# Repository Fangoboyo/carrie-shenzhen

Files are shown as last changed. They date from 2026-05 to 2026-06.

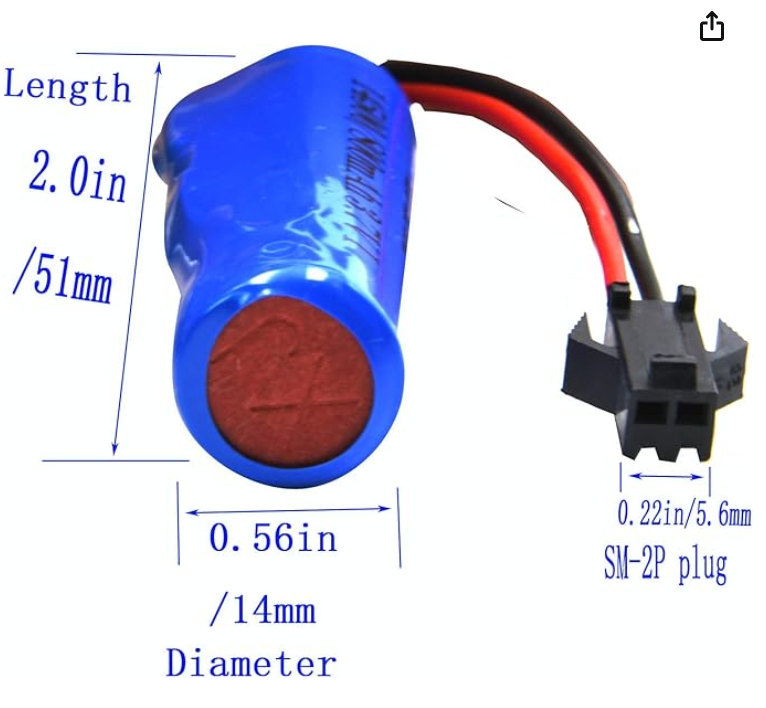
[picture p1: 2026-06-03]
materials/images/Pasted image 20260603162429.png

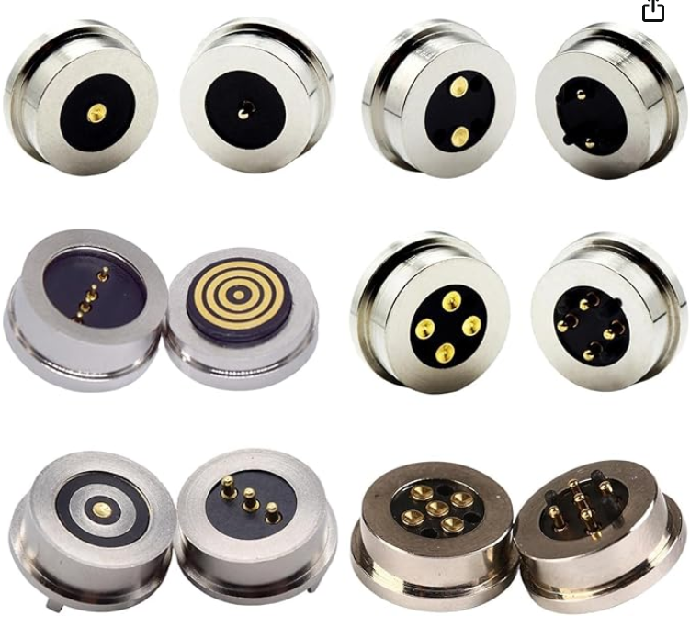
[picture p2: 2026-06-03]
materials/images/Pasted image 20260603162734.png

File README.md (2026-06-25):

# Carrie 🥕 — Embedded Audio/Video Recording Smart Pen

An embedded audio-recording smart pen shaped like a carrot, featuring a custom pot docking station for charging and data transfer. Powered by the Luckfox Pico Mini B (RV1103).

BILL OF MATERIALS IS IN [docs](/docs)



---

## Project Overview

A personal carry device in the shape of a carrot, Carrie is an interpretation of the carrot pen used by Judy Hopps in Zootopia. It's built with a microphone and a camera, integrated into the tiny form factor of a pen, and powered by an embedded Linux microcontroller (Luckfox Pico Mini B) on a custom PCB. With the click of a button, Carrie records 1080p footage at 30 FPS with audio, making sure you never forget to record those memorable moments. Then, simply take off the cap and plug the pen into the pot docking station to transfer your video files to a host computer and charge Carrie's battery.

---

## Why?

All 4 of the team members of this project are High School seniors. At the end of the year, many of the people who we have spent a majority of our lives with will be leaving to colleges across the world. It's easy to say that you'll keep in touch and commit to sending pictures and videos often of what you do everyday, but it's often a promise that is neglected not from a lack of care, but from the nature of experiencing an event; your first thought isn't always to start recording. With a personal carry device in such a form factor, Carrie serves as an always present, physical reminder of that promise. In this way, it helps old friends reconnect and stay connected.

---

## Directory Structure

```
├── docs/                           # Project documentation, Zines, and planning
│   ├── planning/                   # Vault planning notes and Technical Canvas
│   │   ├── notes/                  # Detailed engineering notes (display, GPIO, recording, etc.)
│   │   └── technical_overview.canvas # Visual concept overview
│   ├── bill_of_materials.csv       # Master Bill of Materials (BOM) with links & costs
│   └── zine.pdf                    # Creative project documentation
├── hardware/                       # Mechanical and Electrical designs
│   ├── cad/                        # Fusion 360 & STEP models
│   │   ├── individual_parts/       # Separate CAD files for components
│   │   └── README.md               # CAD specific notes & instructions
│   └── pcb/                        # KiCad PCB designs
│       ├── battery_charger/        # Carrot power regulation and battery charger PCB
│       ├── carry/                  # Main controller and breakout board PCB
│       ├── dirt/                   # Pot wiring junction PCB (V1)
│       └── dirt2/                  # Pot wiring junction PCB (V2)
├── firmware/                       # Source code for microcontrollers
│   ├── carrot/                     # RV1103 C code (Camera, Audio, and GPIO controls)
│   └── pot/                        # ESP8266 display driver code (.ino)
├── materials/                      # Detailed component datasheet notes & summaries
│   ├── bms/                        # Battery Management System notes (MCP73831, DW01A, etc.)
│   ├── images/                     # Component reference photos
│   └── *.md                        # Individual parts summaries (LCD, Microphone, Pogo, etc.)
└── platform/                       # React frontend & PocketBase/Bun backend dashboard
```

---

## Step-by-Step Build & Replication Guide

Follow this guide to replicate both the carrot pen (Carrie) and the docking station (Pot).

---

### 1. Bill of Materials (BOM)
Refer to the detailed master [Bill of Materials](docs/bill_of_materials.csv) for pricing, sourcing links, and specifications.

*   **Compute (Pen):** [Luckfox Pico Mini B (RV1103)](materials/esp32.md) - Linux SBC
*   **Sensor (Pen):** [SC3336 3MP Camera Module](materials/lcd_display.md) (CSI interface)
*   **Audio (Pen):** [SPH0655 Digital MEMS Microphone](materials/microphone.md)
*   **Battery (Pen):** 3.7V 800mAh Li-ion battery (size 14500 cell)
*   **Power (Pen):** Custom charger PCB with [MCP73831T-2A Charger IC](materials/bms/mcp73831.md)
*   **Indicator (Pen):** SunLED XZVGMDK53W-9 (bi-color Red/Green SMD LED)
*   **Compute (Pot):** [ESP8266 Dev Board](materials/esp32.md) (Wemos D1 Mini or similar)
*   **Display (Pot):** [ILI9341 320x240 SPI Touchscreen Display](materials/lcd_display.md)
*   **Docking Junction:** 4-pin Magnetic Contact POGO pins (5V, GND, D+, D-)
*   **Enclosure:** Orange/Green PLA filament, PLA glue.

---

### 2. Schematics & Electrical Design
The electrical system is divided between the Pen and the Pot. Schematics can be reviewed inside the [KiCad PCB Projects](hardware/pcb/).

#### A. The Pen (Carrie)
The pen uses two PCBs:
1.  **Main Board (`hardware/pcb/carry/`):** Hosts the Luckfox Pico Mini B. Routes the camera CSI ribbon, digital MEMS microphone (SPH0655), recording button, and status indicator LEDs.
2.  **Battery Charger Board (`hardware/pcb/battery_charger/`):** Features the [MCP73831T](materials/bms/mcp73831.md) charge controller, protection circuit (DW01A + FS8205A), and matches the bottom shape of the pen where the 4 magnetic contact pads reside.

##### Main Compute Module: Embedded Luckfox Pico Mini B

| Luckfox Pico Mini B (2D Layout) | Luckfox Pico Mini B (3D Render) |
| :---: | :---: |
| luckfox_2d | luckfox_3d |

*Figure 2: The RV1103-based Luckfox Pico Mini B development board used as the central Linux-based camera controller.*

##### Input: Audio & Video

| Microphone Breakout | CSI Camera Module |
| :---: | :---: |
| Microphone Pinout | SC3336 CSI Camera |

*Figure 3: Layouts for the digital SPH0655 MEMS Microphone and the SC3336 3MP CSI camera module.*

##### Power Management: MCP73831T-2A

| Charge Controller Chip | 2D Layout Routing | 3D Board Design |
| :---: | :---: | :---: |
| MCP73831 Chip | PCB 2D Layout | PCB 3D Design |

*Figure 4: The custom power board containing the MCP73831 charge management IC and protection circuits to safely regulate the 14500 Li-ion battery.*

##### Status Indicator: SunLED XZVGMDK53W-9
XZVGMDK53W-9 SMD LED

*Figure 5: Bi-color (Red/Green) SMD status indicator LED for tracking recording states.*

---

#### B. The Pot (Docking Station)
The pot PCB (`hardware/pcb/dirt2/`) aggregates connections for the ESP8266 Dev Board, ILI9341 SPI Display, and a Y-Junction cable to split power and USB data signals.

##### Embedded ESP8266 Board

| 3D Model | 2D Design |
| :---: | :---: |
| ESP8266 3D Model | ESP8266 2D Design |

*Figure 6: Custom PCB interface housing the ESP8266, routing signals to the LCD and decoupling incoming USB lines.*

##### Display: ILI9341
ILI9341 SPI TFT Module

*Figure 7: SPI Serial TFT display used to display system telemetry and connection feedback.*

---

### 3. CAD & Mechanical Assembly
All model assets are stored in [hardware/cad/](hardware/cad/).

#### The Shell

| Camera Side Cutout | Button Side Cutout |
| :---: | :---: |
| Camera Front Face | Button Rear Face |

*Figure 8: Outer mechanical CAD model of the carrot-shaped casing showing camera aperture and button positioning.*

#### Internals

Internal Placement Top

Internal Placement Isometric

*Figure 9: Exploded and internal CAD views highlighting the structural ribs, battery clip, and PCB slots inside the carrot pen.*

#### Flowerpot Dock

| Isometric View | Front Cutaway | Back Enclosure |
| :---: | :---: | :---: |
| Pot Iso | Pot Cutaway | Pot Back |

| Display Bezel Fitting | Base Enclosure Layout | Underneath Routing |
| :---: | :---: | :---: |
| Pot Display Bezel | Pot Inner Board | Pot Routing |

| Receptacle Neck Alignment | | |
| :---: | :---: | :---: |
| Pot Interface | | |

*Figure 10: Assembly CAD breakdowns of the flowerpot dock housing the display, wiring channels, and internal board mounts.*

#### POGO Pins for Data Transfer
We use a magnetic, spring-loaded POGO pin port at the bottom interface of the carrot and inside the pot neck to route data and charge signals.

POGO Pin Configuration

*Figure 11: The 4-pin magnetic layout routing 5V, GND, D+, and D- for toolless charging and storage connection.*

---

### 4. Firmware Build & Flashing Guide

#### A. Pen Firmware (RV1103)
The pen runs Buildroot Linux. Its C firmware is compiled inside a Docker Dev Container to manage target environment dependencies.

1.  **Launch Container:**
    Open the [firmware/carrot/](firmware/carrot/) directory in VS Code. It will prompt you to reopen in the dev container. Under the hood, this loads the `Dockerfile` from [firmware/carrot/.devcontainer/Dockerfile](firmware/carrot/.devcontainer/Dockerfile) which installs the cross-compiler toolchain `arm-rockchip830-linux-uclibcgnueabihf` and Rockchip Media Process Interface (RKMPI) headers.
2.  **Build Code:**
    Run the compile script:
    ```bash
    ./build.sh main
    ```
    This script cross-compiles:
    *   `main.c` (Core thread controller)
    *   `gpio/gpio.c` (Button interrupt and state control)
    *   `recorder/camera_recorder.c` (Uses RKMPI to fetch H.264 video streams from hardware framebuffers)
3.  **Deployment via ADB:**
    The script automatically runs `adb push` over the USB bridge to load the executable into the Luckfox:
    ```bash
    # Pushes binary and marks executable
    adb push main /root/
    adb shell "chmod +x /root/main"
    ```
    To test instantly, run:
    ```bash
    adb shell /root/main
    ```

#### B. Pot Display Firmware (ESP8266)
1.  Open the [firmware/pot/](firmware/pot/) folder in Arduino IDE.
2.  Install the **TFT_eSPI** library through the Library Manager.
3.  Copy/configure the correct pin assignments (CS, DC, RST, LED) in the `User_Setup.h` file located inside the `TFT_eSPI` library folder directory to match the ESP8266 pinout.
4.  Build and upload [displaydriver.ino](firmware/pot/displaydriver.ino) to your ESP8266 over serial USB.

---

### 5. Testing & Verification

1.  **Hardware Self-Test:** Connect the carrot pen to your PC. A solid green light indicates full charge; red/orange indicates active charging.
2.  **GPIO Check:** Run the compiled binary [gpio_input](firmware/carrot/gpio/gpio_input.c) to verify button state changes:
    ```bash
    ./build.sh gpio
    ```
3.  **Video Stream Test:** Run the `recorder` profile to verify image sensor capture and H.264 stream writing:
    ```bash
    ./build.sh recorder
    # Run on board: adb shell /root/camera_recorder_demo
    ```
4.  **Full Loop Recording:** Tap the physical button on the carrot casing. The indicator LED flashes to signal recording. Push the button again to stop.
5.  **Docking & Transfer:** Dock the pen in the Pot. The LCD screen should light up, showing connection telemetry. The PC will recognize a USB mass storage device or an ADB network interface. 
6.  **Web Dashboard Sync:** Start the React platform. Use the dashboard to fetch files from the docked pen and stream them directly onto Google Drive.
### Web Platform Dashboard
Okay I'm going to cut the formal documentation-speech for this part because im genuinely so proud of this website, it lets you plug your pot directly into your computer, and the browser is able to take the datastream from the USB and directly upload it to youtube for infinite free storage. All of the components are super animated like the books float and flip on their own, they rotate, they blur, all done with just tailwind. It genuinely took such a long time but adds an incredibly integrated aspect of the project that just brings everything together.

Web Platform Dashboard Mockup

*Figure 1: React-based web dashboard displaying scrapbook video feeds synced from the carrot pen.*

For more details on the design, code operations, and custom hardware modules, see the docs folder, where obsidian canvases draw out everything overviewing the project.

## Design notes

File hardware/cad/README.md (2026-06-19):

\#CAD README

\##General Notes

The entire CAD can be found in the FINAL files.

The models are split into parts, and are meant to be printed the way they are separated (one side of carrot, other half, one half of pot, other half, and individual parts that are inserted).

Pictures of complete models and renders of the carrot and the pot can be found in the main README file.

Individual parts are found in the Individual Parts Folder. 

Some individual parts don't contain their own file, and are in other files (such as some of the mounting/holding mechanisms, which exist in the carrot file).

There are some parts that are just created within the FINAL file, and do not exist in any other file.

\##Part Mounting/Connecting Parts

During testing, we found that due to the size of our project and the size of the printer nozzle, all of the joints that we created were extremely weak. This made us resort to testing just using the friction between the parts, which while working, are not reliable.

To fortify this approach, when we build our project, we will utilize 3D modeling glue (PLA glue), to directly create a connection in addition to cylindrical connectors. 

\##Parts

Some of the parts in the build are not apart of what is 3D printed. In the Carrot, you will see 3 rectangular boxes, with the middle one with some stuff sticking out. Those 3 are just placeholders for where our RV1103 Pico Mini Linux SBC, Carry PCB, and Battery Regulator will be. 

The battery will be placed in the battery holder, and will be stopped on the top by the part on the other side of the carrot, so there is no vertical movement.

The camera is held at the top of the carrot (toward the leaf), with cylinders that fit inside it's mounting holes, and is slotted in there.

The PCB and microcontroller for the Pot will be slotted at the bottom of the Pot.

The PCB and microcontroller for both the Pot and the Carrot will be connected to each other via pin headers. These pin headers will be cut to be shorter than standard size, in order to fit inside compartments. 

Components will be connected to each other via wiring and soldering. 

The Cap and the Leaf are attached using a the coil method (like a bottle cap).

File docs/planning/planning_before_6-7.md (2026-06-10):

Albert - solidify component list
what components would we use
why use this one
why others wont work

Youcheng
ORDER PCB

Q1: How can we rework the MCP pin to be off of the PCB in order to make a seperate breakout board regulator

![[Pasted image 20260605001627.png]]

Q2: explain what the STAT pin does IN DETAIL PLEASE (voltage? current direction?) why are specific resistance values picked. Schematic should be corrected. Details of each part of the PCB needs to be documented. (maybe push some documentation onto the obsidian project??)

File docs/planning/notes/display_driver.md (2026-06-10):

```c++
#include <SPI.h>
#include <TFT_eSPI.h>

// Invoke the library. It automatically pulls the pins from User_Setup.h
TFT_eSPI tft = TFT_eSPI(); 

void setup() {
  Serial.begin(115200);

  // 1. Initialize the hardware SPI bus and the display
  tft.init();

  // 2. Set screen rotation 
  // 0 = Portrait, 1 = Landscape, 2 = Portrait Inverted, 3 = Landscape Inverted
  tft.setRotation(1);

  // 3. Clear the screen to a solid color
  tft.fillScreen(TFT_BLACK);

  // --- DRAWING THE INTERFACE ---

  // Draw a top status bar
  tft.fillRect(0, 0, 320, 30, TFT_BLUE); 

  // Setup text formatting
  tft.setTextColor(TFT_WHITE, TFT_BLUE); // Foreground, Background (prevents text overlapping mess)
  tft.setTextSize(2); // Multiplier of the base font size
  
  // Print text to the status bar
  tft.setCursor(10, 8);
  tft.println("SYSTEM ONLINE");

  // Placeholder
  tft.setTextColor(TFT_GREEN, TFT_BLACK);
  tft.setTextSize(3);
  tft.setCursor(10, 60);
  tft.println("Temp: 42 C");
}

void loop() {
}
```

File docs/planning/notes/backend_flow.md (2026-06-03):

# System Architecture

## Backend Flow

The backend is built with Bun's native HTTP server (`Bun.serve`) and a local `bun:sqlite` database. It handles Google OAuth, session management, and piping uploads directly to the Google Drive API.

```mermaid
sequenceDiagram
    participant Client
    participant Server as Bun Server
    participant DB as SQLite DB
    participant GoogleAuth as Google OAuth
    participant GoogleDrive as Google Drive API

    %% Authentication Flow
    rect rgb(240, 248, 255)
        Note over Client, GoogleAuth: 1. Authentication & Session
        Client->>Server: GET /auth/google
        Server-->>Client: 302 Redirect to Google Auth URL
        Client->>GoogleAuth: User logs in & grants consent
        GoogleAuth-->>Server: GET /auth/callback?code=xyz
        Server->>GoogleAuth: Exchange code for Tokens
        GoogleAuth-->>Server: Access & Refresh Tokens
        Server->>DB: Upsert User & Generate API Key
        Server-->>Client: Set Session Cookie & Redirect to /
    end

    %% Feed Retrieval Flow
    rect rgb(255, 250, 240)
        Note over Client, DB: 2. Initial Data Load
        Client->>Server: GET /api/me (with Cookie)
        Server->>DB: Lookup user by Cookie ID
        DB-->>Server: User Data & API Key
        Server-->>Client: JSON { user }
        
        Client->>Server: GET /api/videos
        Server->>DB: SELECT * FROM videos JOIN users
        DB-->>Server: Feed Data
        Server-->>Client: JSON [ videos ]
    end

    %% Upload Flow
    rect rgb(240, 255, 240)
        Note over Client, GoogleDrive: 3. Video Upload
        Client->>Server: POST /api/upload (File + Bearer API_KEY)
        Server->>DB: Verify API_KEY
        DB-->>Server: Valid User Tokens
        Server->>GoogleDrive: Pipe File Stream (create)
        GoogleDrive-->>Server: Return Google Drive File ID
        Server->>DB: INSERT INTO videos (file_id, user_id)
        Server-->>Client: 200 OK (Upload Successful)
    end
```

[[Frontend Flow]]

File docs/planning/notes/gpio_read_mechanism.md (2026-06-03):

Before reading from a pin, a GPIO pin needs to be exported:
```C
int gpio_export(int gpio)
{
    char dir[80];
    snprintf(dir, sizeof(dir), GPIO_ROOT "/gpio%d", gpio);
    if (access(dir, F_OK) == 0) return 0;   /* already exported */

    char buf[16];
    snprintf(buf, sizeof(buf), "%d", gpio);
    if (sysfs_write(GPIO_ROOT "/export", buf) < 0) {
        fprintf(stderr, "  [!] Export failed — is gpio%d valid on this kernel?\n", gpio);
        return -1;
    }
    return 0;
}
```

 ` snprintf` writes data into char array `buf`. This is necessary because the way you read GPIO pins in a Linux based development board is through accessing the GPIO file.

After the pin is exported, it is read through:
```C
int gpio_read(int gpio)
{
    char path[80];
    snprintf(path, sizeof(path), GPIO_ROOT "/gpio%d/value", gpio);
    FILE *f = fopen(path, "r");
    if (!f) { perror("  [!] read value"); return -1; }
    
    int v = -1;
    fscanf(f, "%d", &v);
    fclose(f);
    return v;
}
```

taking the output of `/gpio%d/value` as a file and returning it as a value

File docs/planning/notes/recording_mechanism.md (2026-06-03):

#### Writer Thread
Each iteration of the recording loop dequeues one encoded stream packet from the Video Encoder (VENC) channel, writes it to disk, then releases the buffer back to the codec.  `RK_MPI_VENC_GetStream()` blocks up to `timeout_ms` milliseconds, so the thread is never busy-spinning.

```c
VENC_STREAM_S stream;
VENC_PACK_S   packs[8];
memset(&stream, 0, sizeof(stream));
memset(packs, 0, sizeof(packs));
stream.pstPack = packs;
```

After initializing the stream and pack with values 0, we get the next available frame:

```c
RK_S32 ret = RK_MPI_VENC_GetStream(g_cfg.venc_chn, &stream, timeout_ms);
```

`RK_MPI_VENC_GetStream` gets the next available frame from the `g_cfg.venc_chn` which is our main channel, into our `VENC_STREAM_S stream` with a timeout.

We then check if the frame was successfully retrieved:

```c
if (ret == RK_ERR_VENC_BUF_EMPTY) {
	/* No frame ready yet — loop and try again */
    continue;
}
if (ret != RK_SUCCESS) {
    LOG_ERR("RK_MPI_VENC_GetStream failed (0x%08x)", (unsigned)ret);
    break;
}
```

After the frame is output into our buffer, we can start "stitching" the packets together, by looping through the Network Abstraction Layer (NAL) units and:

```c
VENC_PACK_S *pack = &stream.pstPack[i]; // current packet in loop

void *data = RK_MPI_MB_Handle2VirAddr(pack->pMbBlk);
```

The Rockchip hardware encoder operates in physical memory. It drops the video data into a hardware memory block `pMbBlk`.

The C program runs in Linux "user space" and cannot directly touch physical hardware memory.

`RK_MPI_MB_Handle2VirAddr` acts as a translator. It takes the hardware's memory handle and gives back a standard C pointer (data - a "Virtual Address") that your CPU can safely read. Essentially, giving an API representation that lets you interact with the hardware memory across the linux abstraction layer.

Finally, we can validate the packet packet length is not empty through `pack->u32Len (Memory length) > 0` and `data (Memory address) != null`. If this is validated, we can then write into the `g_out_file` from address `data` for `pack->u32Len` length of data.

```c
if (pack->u32Len > 0 && data != NULL) { fwrite(data, 1, pack->u32Len, g_out_file); }
```

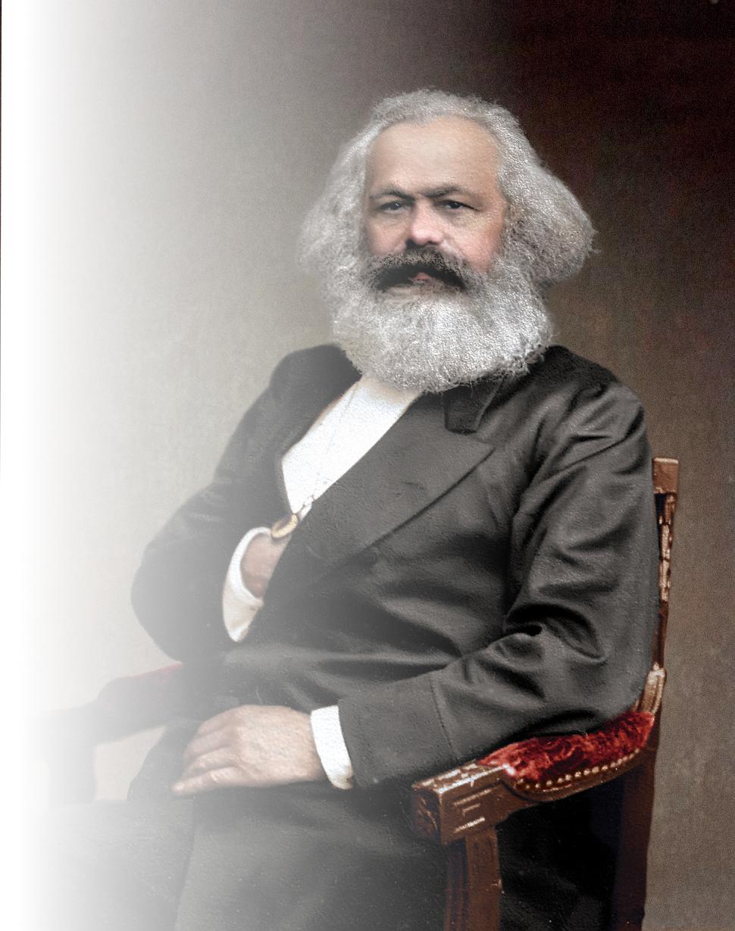
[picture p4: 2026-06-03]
platform/src/assets/marx.png

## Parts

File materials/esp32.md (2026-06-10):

[Amazon](https://www.amazon.com/dp/B081CSJV2V?ref_=ppx_hzsearch_conn_dt_b_fed_asin_title_2)

[[LCD Display (Touchscreen) - Arrived]] Takes:

| ESP Pin | Touchscreen |
| --- | --- |
| 3v3 | VCC |
| 3v3 | LED |
| GND | GND |

![[Pasted image 20260603140626.png]]

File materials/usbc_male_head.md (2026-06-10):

Stripped male head of a USBC cable, with the D+/- exposed

Plugs into the USBC female port on the development board
![[Pasted image 20260604230423.png]]

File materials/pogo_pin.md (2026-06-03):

[Amazon](https://www.amazon.com/Magnetic-Connector-Female-Socket-Charging/dp/B0DJ26RV19/ref=sr_1_6?sr=8-6&th=1)

| PIN | Usage |
| --- | --- |
| D+ | D+ on USBC Male -> POGO -> Dirt pile |
| D- | D- on USBC Male -> POGO -> Dirt pile |
| 5V VBUS | Dirt Pile -> POGO -> Battery Regulator |
| GND | Dirt Pile -> POGO -> Battery Regulator |
![[Pasted image 20260603162734.png]]

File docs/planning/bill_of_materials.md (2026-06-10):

[[LCD Display (Touchscreen) - Arrived]]
[[POGO Pin - Arrived]]
[[ESP32 - Arrived]]
[[Microphone - Arrived]]

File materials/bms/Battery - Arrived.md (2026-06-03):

[Amazon](https://www.amazon.com/Blomiky-Rechargeable-Battery-Charger-Amphibious/dp/B08Q45XQKW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)

![[Pasted image 20260603162429.png]]

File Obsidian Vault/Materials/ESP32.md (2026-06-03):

[Amazon](https://www.amazon.com/dp/B081CSJV2V?ref_=ppx_hzsearch_conn_dt_b_fed_asin_title_2)

[[LCD Display (Touchscreen)]] Takes:

| ESP Pin | Touchscreen |
| --- | --- |
| 3v3 | VCC |
| 3v3 | LED |
| GND | GND |

![[Pasted image 20260603140626.png]]

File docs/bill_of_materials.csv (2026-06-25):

Part Name | Unit Part Price ($) | Unit Part Count | Part Cost Total ($) | Description | Part Link | Total:
RV1103 Pico Mini Linux SBC | 15 | 1 | 15 | Linux-based microcontroller board used as the main processing unit for dealing with audo/video recording and handles data | https://www.amazon.com/dp/B0CSSZFRR3 | 98.65
SPH0655 Digital MEMS Microphone | 1.69 | 1 | 1.69 | High-sensitivity digital MEMS microphone used for capturing voice an audio | https://www.digikey.com/en/products/detail/syntiant/SPH0655LM4H-1-8/11506911
SC3336 3MP Camera Module | 12.89 | 1 | 12.89 | 3MP compact camera module for capturing images and video footage | https://osoyoo.store/products/osoyoo-basic-starter-kit-with-uno-board-for-arduino-electronic-projects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
MCP73831T-2ACI/OT | 0.76 | 1 | 0.76 | Charger IC Lithium Ion/Polymer SOT-23-5 | https://www.digikey.com/en/products/detail/microchip-technology/MCP73831T-2ACI-OT/964301
SunLED XZVGMDK53W-9 | 0.35 | 1 | 0.35 | Green, Red 570nm Green, 630nm Red LED Indication - Discrete 2.1V Green, 1.95V Red 0603 (1608 Metric) | https://www.digikey.com/en/products/detail/sunled/XZVGMDK53W-9/8259057
Touch Screen Shield Display Module 320x240 SPI Serial ILI9341 with Touch Pen | 14.99 | 1 | 14.99 | Resistance based touchscreen LCD | https://www.amazon.com/Hosyond-Display-320x240-Compatible-Development/dp/B09XHJ9KRX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
Button | 5 | 1 | 5 | Simple electrical button | https://www.amazon.com/DAOKI-100Pcs-6x6x5mm-Momentary-Tactile/dp/B07X8T9D2Q?s=industrial
Orange PLA filament | 14.99 | 1 | 14.99 | 3D Printing Filament | https://www.amazon.com/Miailuy-Filament-Tangle-Free-Clog-Free-Compatibility/dp/B0FN46ZXRB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
PLA Glue | 8 | 1 | 8 | 3D Printing glue for PLA (casing needs to be glued together due to size restrictions preventing screw usage | https://www.amazon.com/ALECPEA-Printer-Glue-Resin-Models/dp/B0G3WYT51V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
Blomiky 2 Pack 3.7V 800mAh Li-ion Rechargeable Battery | 9.99 | 1 | 9.99 | 3.7V 800 mAh battery to power the carrot's microcontroller | https://www.amazon.com/Blomiky-Rechargeable-Battery-Charger-Amphibious/dp/B08Q45XQKW
ESP8266 | 14.99 | 1 | 14.99 | Microcontroller on the pot/holster to drive the touchscreen display | https://www.amazon.com/Hosyond-Wireless-Development-Compatible-Micropython/dp/B09SPWYS4B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

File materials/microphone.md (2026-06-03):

[Amazon](https://www.amazon.com/Adafruit-I2S-MEMS-Microphone-Breakout/dp/B06XNL2GBW)

![[Pasted image 20260603163029.png]]

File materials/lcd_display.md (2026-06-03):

[Amazon](https://www.amazon.com/Hosyond-Display-320x240-Compatible-Development/dp/B09XHJ9KRX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)

![[Pasted image 20260603153835.png]]

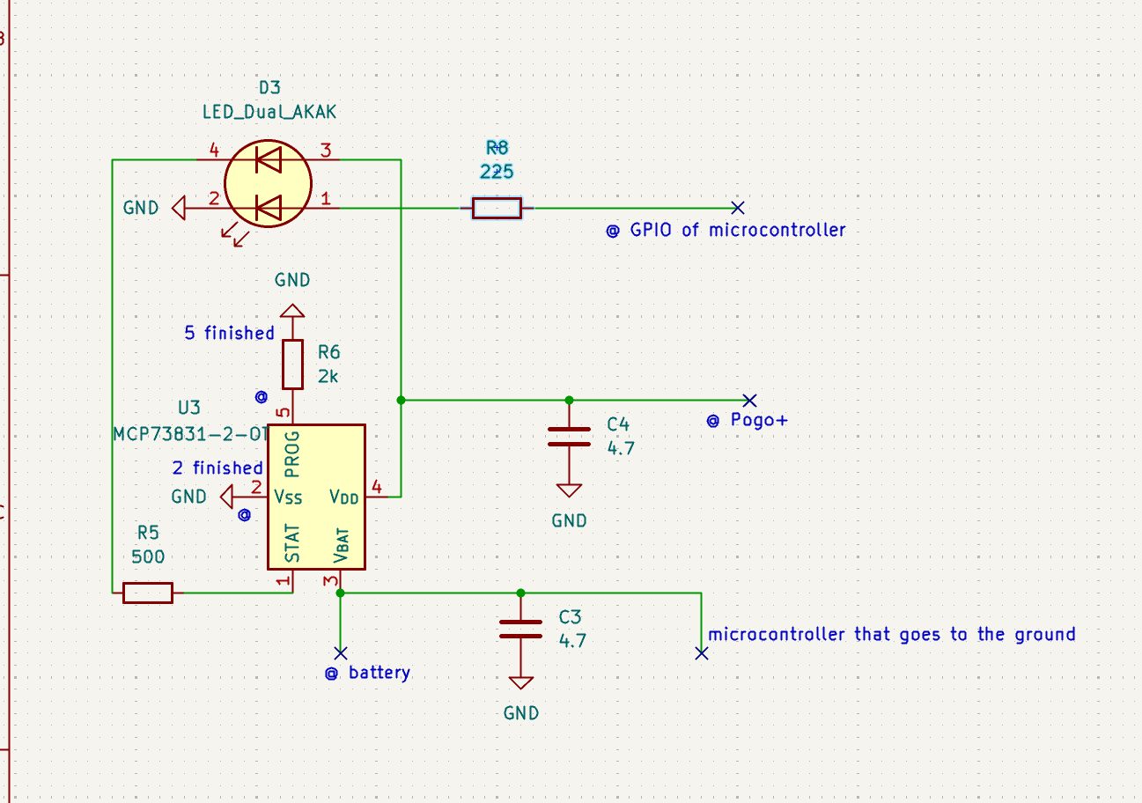
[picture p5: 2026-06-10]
materials/images/Pasted image 20260605001627.png

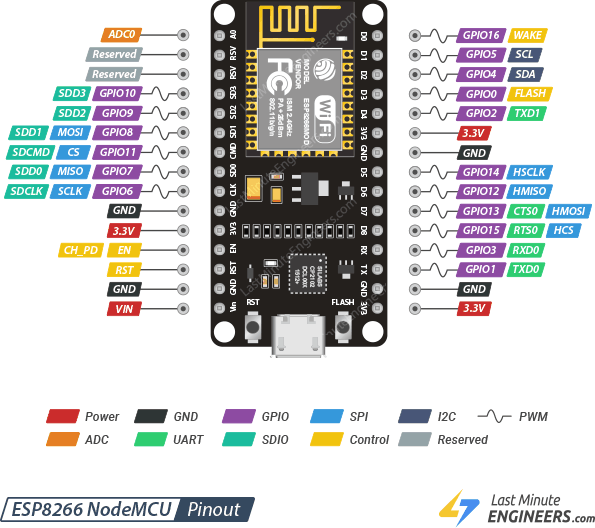
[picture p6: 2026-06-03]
materials/images/Pasted image 20260603140626.png

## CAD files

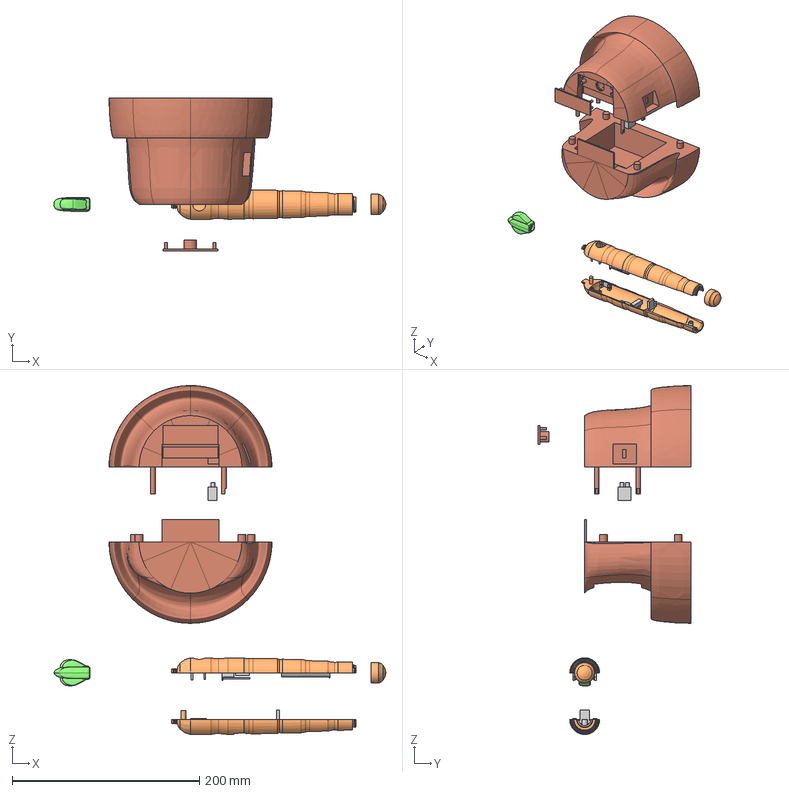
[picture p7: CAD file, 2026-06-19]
hardware/cad/FINAL.step
354.8 x 163.7 x 373.2 mm

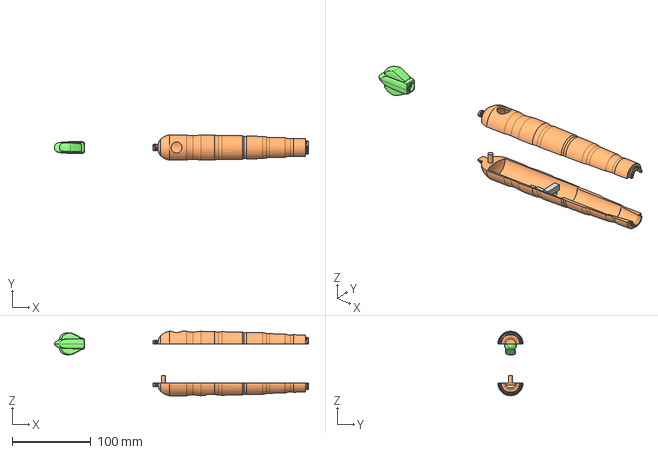
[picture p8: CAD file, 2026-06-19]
hardware/cad/individual_parts/Carrot.step
322.6 x 32.0 x 82.0 mm

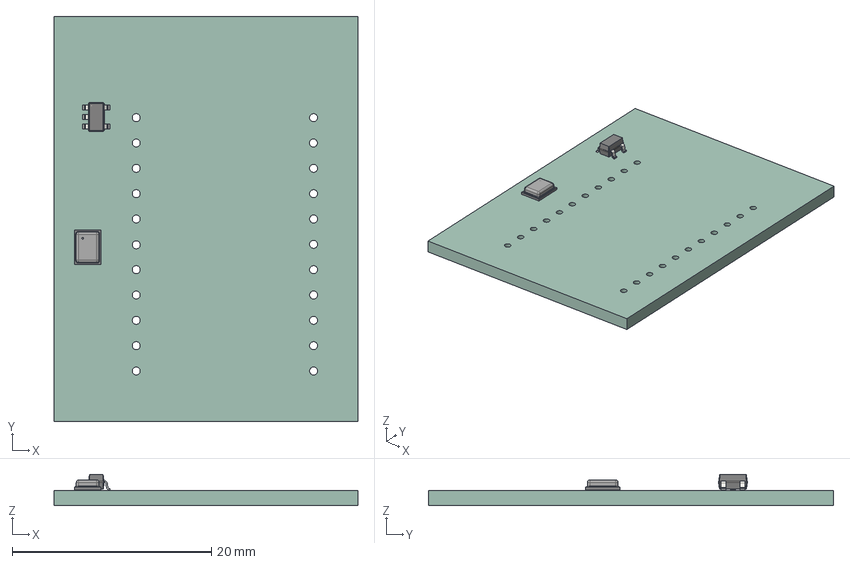
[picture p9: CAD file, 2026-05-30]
hardware/pcb/carry/.step
30.5 x 40.6 x 3.15 mm
SOT-23-5
Knowles_SPH0645LM4H-6_3.5x2.65mm
Carry_PCB

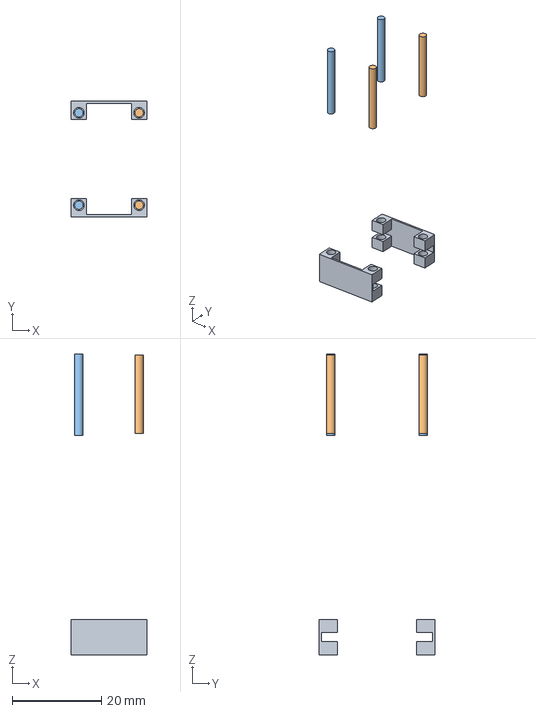
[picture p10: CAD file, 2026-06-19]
hardware/cad/individual_parts/Camera Support.step
17.0 x 26.0 x 67.5 mm

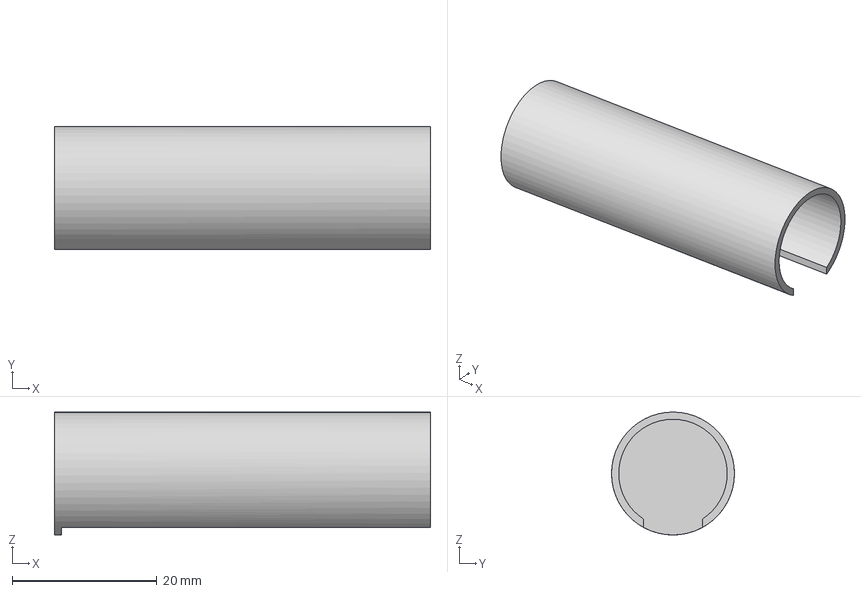
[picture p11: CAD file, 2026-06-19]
hardware/cad/individual_parts/Battery Holder.step
52.0 x 17.0 x 17.0 mm

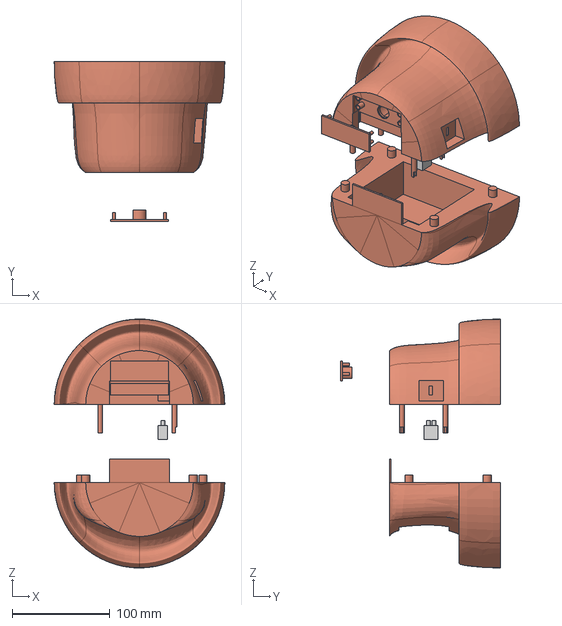
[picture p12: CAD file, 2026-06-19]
hardware/cad/individual_parts/Pot.step
174.3 x 163.7 x 254.3 mm

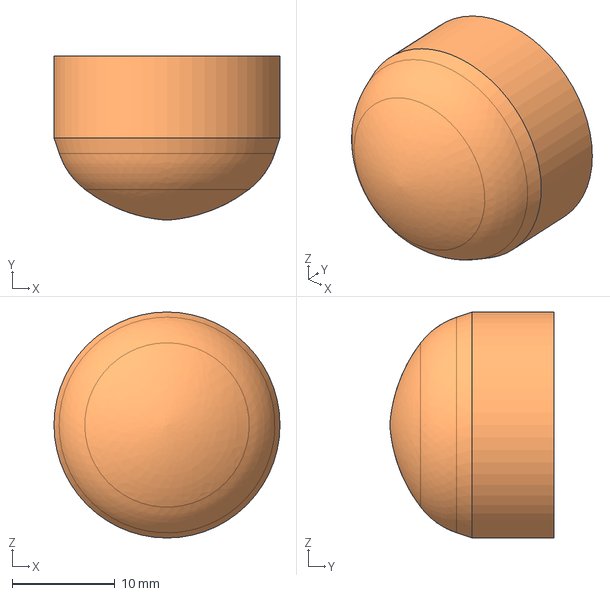
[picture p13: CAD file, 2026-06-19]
hardware/cad/individual_parts/Cap.step
22.0 x 16.0 x 22.0 mm

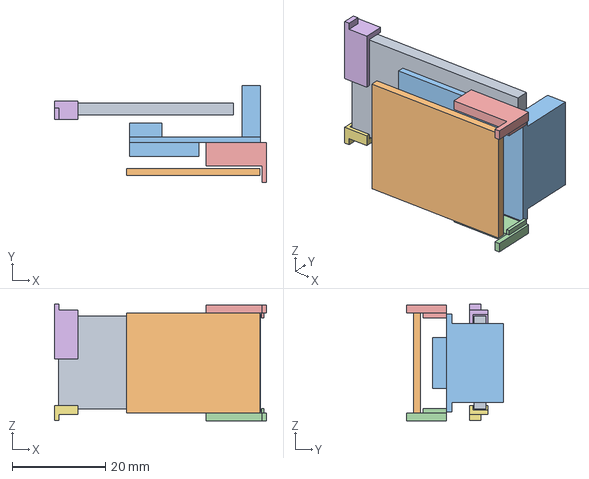
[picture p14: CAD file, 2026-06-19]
hardware/cad/individual_parts/PCB Slot.step
45.5 x 20.8 x 25.1 mm

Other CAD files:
hardware/cad/individual_parts/Battery Holder.f3d
hardware/cad/individual_parts/Camera Support.f3d
hardware/cad/individual_parts/Cap.f3d
hardware/cad/individual_parts/Carrot.f3d
hardware/cad/individual_parts/PCB Slot.f3d
hardware/cad/individual_parts/Pot.f3d

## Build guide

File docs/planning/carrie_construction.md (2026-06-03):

[[Technical overview.canvas]]

| Color | Significance |
| ----- | --- |
| Red | Power |
| Blue  | Data |
| Green | Display |

|     |
| --- |
|     |

[[Bill of Materials]]

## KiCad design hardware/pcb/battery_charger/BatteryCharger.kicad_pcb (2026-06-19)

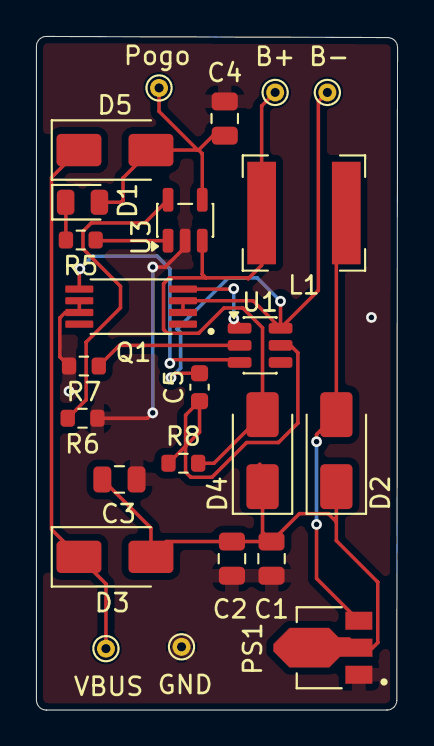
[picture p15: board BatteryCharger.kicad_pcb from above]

Board: 2 copper layers, 20.1 x 37.4 mm, 24 parts (0 on the bottom side), 14 nets.

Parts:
B+: B+; TestPoint_THTPad_D1.0mm_Drill0.5mm
B-: B-; TestPoint_THTPad_D1.0mm_Drill0.5mm
C1, C2: 12; C_0805_2012Metric
C3, C4: 4.7; C_0805_2012Metric
C5: 0.1; C_0603_1608Metric
D1: LED; LED_0805_2012Metric
D2, D3, D4, D5: SS14; D_SMA
GND: B-; TestPoint_THTPad_D1.0mm_Drill0.5mm
L1: 22; L_Bourns-SRN6028
PS1: ME2108A33P
Pogo: Pogo+; TestPoint_THTPad_D1.0mm_Drill0.5mm
Q1: FS8205A
R5: 470; R_0603_1608Metric
R6: 2k; R_0603_1608Metric
R7: 1k; R_0603_1608Metric
R8: 100; R_0603_1608Metric
U1: DW01A; SOT-23-6
U3: MCP73831; SOT-23-5
VBUS: Output 5V; TestPoint_THTPad_D1.0mm_Drill0.5mm

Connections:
GND: C1.2, C2.2, C3.2, C4.2, GND.1 (1_1), PS1.1 (VSS), Q1.6, Q1.7, R6.1, R7.2, U3.2 (V_{SS})
unnamed: C4.1, D1.2 (A), D5.2 (A), Pogo.1 (1_1), U3.4 (V_{DD})
unnamed: D1.1 (K), R5.2
unnamed: D2.2 (A), L1.2, PS1.3 (LX)
unnamed: C1.1, C2.1, C3.1, D2.1 (K), D3.2 (A), D4.1 (K), PS1.2 (VOUT)
unnamed: D3.1 (K), D5.1 (K), VBUS.1 (1_1)
unnamed: B+.1 (1_1), D4.2 (A), L1.1, R8.1, U3.3 (V_{BAT})
unnamed: R7.1, U1.2 (CS)
unnamed: B-.1 (1_1), C5.2, Q1.2, Q1.3, U1.6 (GND)
unnamed: Q1.5, U1.3 (OC)
unnamed: Q1.4, U1.1 (OD)
unnamed: C5.1, R8.2, U1.5 (VCC)
unnamed: R6.2, U3.5 (PROG)
unnamed: R5.1, U3.1 (STAT)

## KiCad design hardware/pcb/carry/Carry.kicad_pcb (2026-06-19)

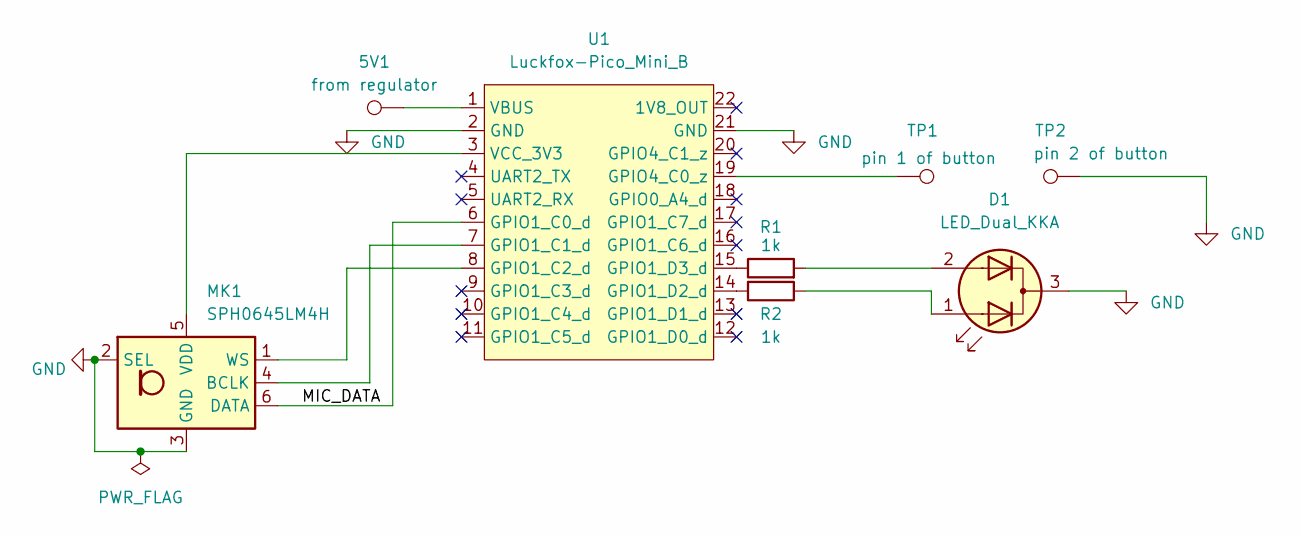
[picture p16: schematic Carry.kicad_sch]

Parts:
5V1: from regulator; TestPoint_THTPad_D1.0mm_Drill0.5mm
D1: LED_Dual_KKA; LED-L1T2_LUMILEDS
MK1: SPH0645LM4H; Knowles_SPH0645LM4H-6_3.5x2.65mm
R1, R2: 1k
TP1: pin 1 of button; TestPoint_THTPad_D1.0mm_Drill0.5mm
TP2: pin 2 of button; TestPoint_THTPad_D1.0mm_Drill0.5mm
U1: Luckfox-Pico_Mini_B; Luckfox_Pico_Mini_B

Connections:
/MIC_DATA: MK1.6 (DATA), U1.6 (GPIO1_C0_d)
GND: D1.3 (K), MK1.2 (SEL), MK1.3 (GND), TP2.1 (1_1), U1.2 (GND), U1.21 (GND)
unnamed: D1.1 (A1), R2.1
unnamed: D1.2 (A2), R1.2
unnamed: MK1.4 (BCLK), U1.7 (GPIO1_C1_d)
unnamed: MK1.5 (VDD), U1.3 (VCC_3V3)
unnamed: MK1.1 (WS), U1.8 (GPIO1_C2_d)
unnamed: R2.2, U1.14 (GPIO1_D2_d)
unnamed: R1.1, U1.15 (GPIO1_D3_d)
unnamed: TP1.1 (1_1), U1.19 (GPIO4_C0_z)
unnamed: 5V1.1 (1_1), U1.1 (VBUS)

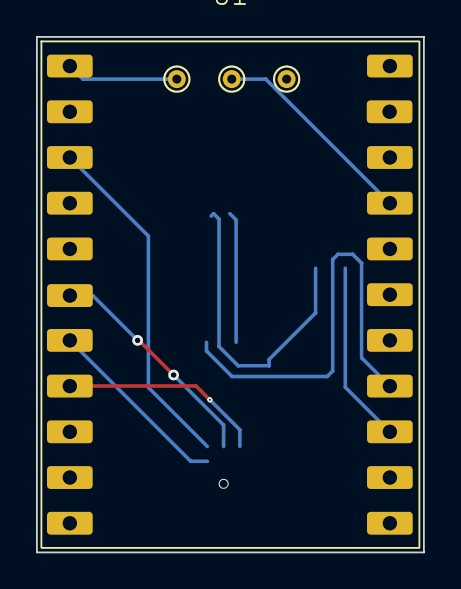
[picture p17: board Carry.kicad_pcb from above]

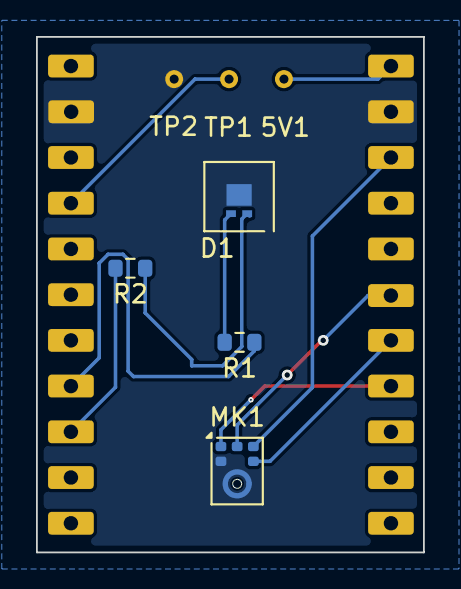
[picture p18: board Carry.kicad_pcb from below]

Board: 2 copper layers, 21.5 x 28.6 mm, 8 parts (4 on the bottom side), 11 nets.

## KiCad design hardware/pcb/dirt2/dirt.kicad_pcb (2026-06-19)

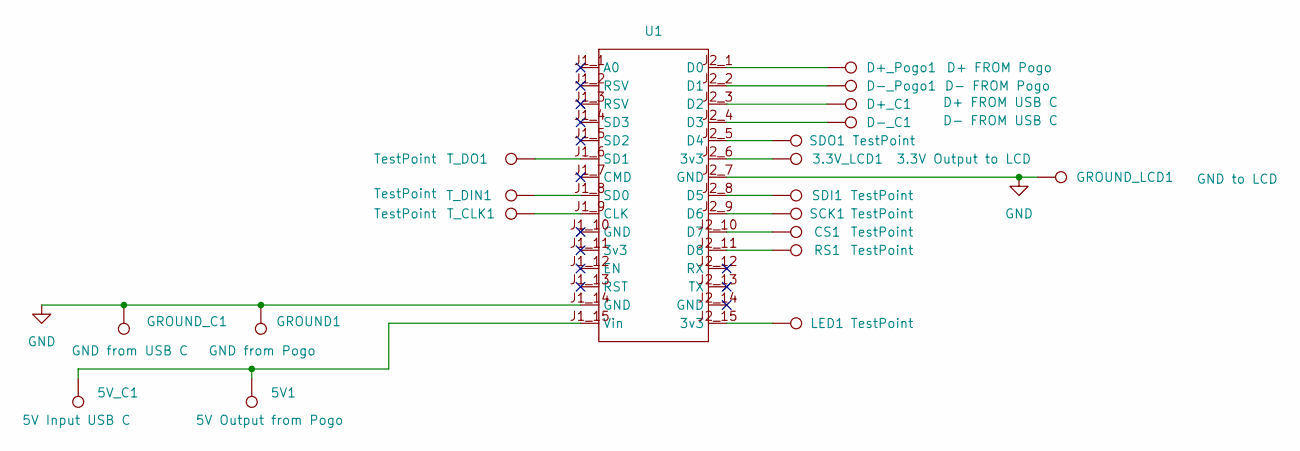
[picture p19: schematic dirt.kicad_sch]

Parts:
3.3V_LCD1: 3.3V Output to LCD; TestPoint_THTPad_D1.0mm_Drill0.5mm
5V1: 5V Output from Pogo; TestPoint_THTPad_D1.0mm_Drill0.5mm
5V_C1: 5V Input USB C; TestPoint_THTPad_D1.0mm_Drill0.5mm
CS1: TestPoint; TestPoint_THTPad_D1.0mm_Drill0.5mm
D+_C1: D+ FROM USB C; TestPoint_THTPad_D1.0mm_Drill0.5mm
D+_Pogo1: D+ FROM Pogo; TestPoint_THTPad_D1.0mm_Drill0.5mm
D-_C1: D- FROM USB C; TestPoint_THTPad_D1.0mm_Drill0.5mm
D-_Pogo1: D- FROM Pogo; TestPoint_THTPad_D1.0mm_Drill0.5mm
GROUND1: GND from Pogo; TestPoint_THTPad_D1.0mm_Drill0.5mm
GROUND_C1: GND from USB C; TestPoint_THTPad_D1.0mm_Drill0.5mm
GROUND_LCD1: GND to LCD; TestPoint_THTPad_D1.0mm_Drill0.5mm
LED1: TestPoint
RS1: TestPoint; TestPoint_THTPad_D1.0mm_Drill0.5mm
SCK1: TestPoint; TestPoint_THTPad_D1.0mm_Drill0.5mm
SDI1: TestPoint; TestPoint_THTPad_D1.0mm_Drill0.5mm
SDO1: TestPoint; TestPoint_THTPad_D1.0mm_Drill0.5mm
T_CLK1: TestPoint; TestPoint_THTPad_D1.0mm_Drill0.5mm
T_DIN1: TestPoint; TestPoint_THTPad_D1.0mm_Drill0.5mm
T_DO1: TestPoint; TestPoint_THTPad_D1.0mm_Drill0.5mm
U1: (no value)

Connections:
GND: GROUND1.1 (1_1), GROUND_C1.1 (1_1), GROUND_LCD1.1 (1_1), U1.J1_14 (GND), U1.J2_7 (GND)
unnamed: 3.3V_LCD1.1 (1_1), U1.J2_6 (3v3)
unnamed: LED1.1, U1.J2_15 (3v3)
unnamed: T_CLK1.1 (1_1), U1.J1_9 (CLK)
unnamed: D+_Pogo1.1 (1_1), U1.J2_1 (D0)
unnamed: D-_Pogo1.1 (1_1), U1.J2_2 (D1)
unnamed: D+_C1.1 (1_1), U1.J2_3 (D2)
unnamed: D-_C1.1 (1_1), U1.J2_4 (D3)
unnamed: SDO1.1 (1_1), U1.J2_5 (D4)
unnamed: SDI1.1 (1_1), U1.J2_8 (D5)
unnamed: SCK1.1 (1_1), U1.J2_9 (D6)
unnamed: CS1.1 (1_1), U1.J2_10 (D7)
unnamed: RS1.1 (1_1), U1.J2_11 (D8)
unnamed: T_DIN1.1 (1_1), U1.J1_8 (SD0)
unnamed: T_DO1.1 (1_1), U1.J1_6 (SD1)
unnamed: 5V1.1 (1_1), 5V_C1.1 (1_1), U1.J1_15 (Vin)

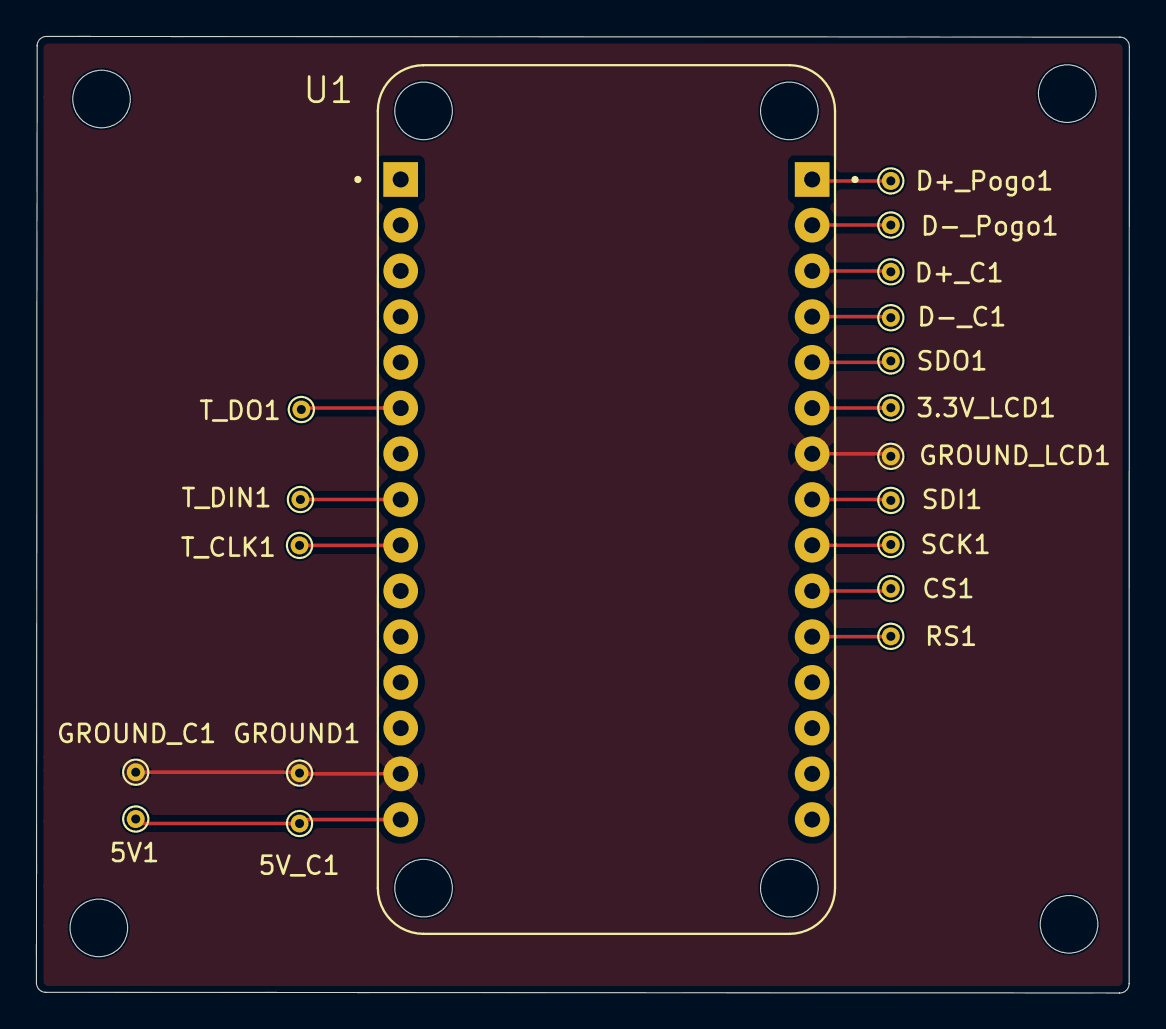
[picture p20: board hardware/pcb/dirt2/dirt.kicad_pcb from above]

Board: 2 copper layers, 60.7 x 53.1 mm, 19 parts (0 on the bottom side), 15 nets.

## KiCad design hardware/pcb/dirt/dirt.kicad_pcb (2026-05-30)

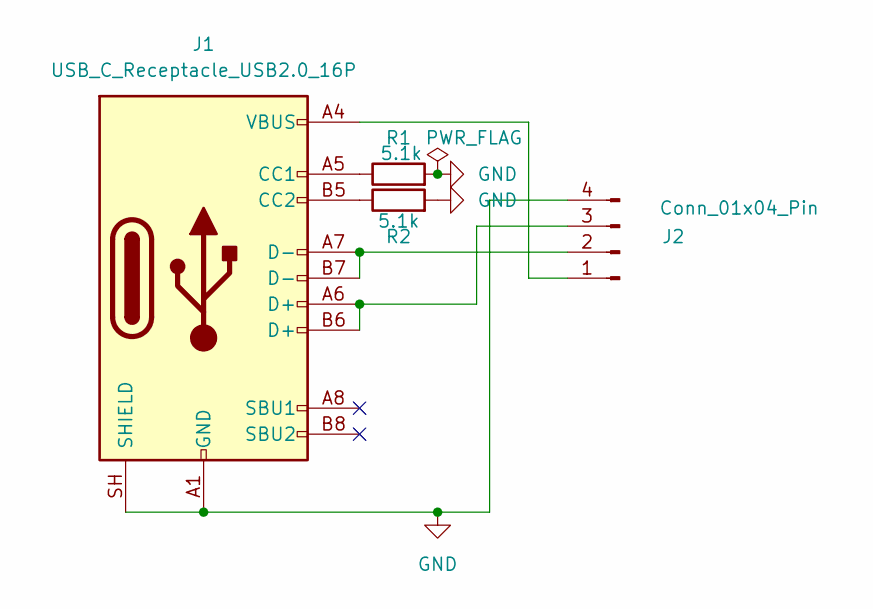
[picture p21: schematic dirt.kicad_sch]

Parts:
J1: USB_C_Receptacle_USB2.0_16P; USB_C_Receptacle_HRO_TYPE-C-31-M-12
J2: Conn_01x04_Pin; PinHeader_1x04_P2.54mm_Vertical_SMD_Pin1Left
R1, R2: 5.1k; R_0805_2012Metric

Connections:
GND: J1.A1 (GND), J1.A12 (GND), J1.B1 (GND), J1.B12 (GND), J1.SH (SHIELD), J2.4, R1.2, R2.2
unnamed: J1.A5 (CC1), R1.1
unnamed: J1.B5 (CC2), R2.1
unnamed: J1.A4 (VBUS), J1.A9 (VBUS), J1.B4 (VBUS), J1.B9 (VBUS), J2.1
unnamed: J1.A7 (D-), J1.B7 (D-), J2.2
unnamed: J1.A6 (D+), J1.B6 (D+), J2.3

Board: 2 copper layers, 4 parts (0 on the bottom side), 6 nets, no tracks yet.

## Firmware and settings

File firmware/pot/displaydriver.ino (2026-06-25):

#include <SPI.h>
#include <TFT_eSPI.h>

TFT_eSPI tft = TFT_eSPI();

// UI State variables
enum SystemState {
  STATE_DISCONNECTED,
  STATE_CONNECTED,
  STATE_SYNCING,
  STATE_SYNC_COMPLETE,
  STATE_EJECTED
};

SystemState currentState = STATE_CONNECTED;
SystemState previousState = STATE_DISCONNECTED;

// Telemetry state
int batteryPercent = 78;
float batteryVoltage = 3.92;
int chargeCurrent = 420; // mA
int syncProgress = 0;
String currentSyncFile = "video_03.h264";

// Interactive Backlight dummy state
bool backlightOn = true;

// Timing variables for simulation
unsigned long lastUpdate = 0;
unsigned long lastTouchDebounce = 0;

void setup() {
  Serial.begin(115200);
  tft.init();
  tft.setRotation(1); // Landscape (320x240)
  tft.fillScreen(TFT_BLACK);
  
  // Calibrate touch sensor (default coordinates mapping)
  uint16_t calData[5] = { 275, 3620, 264, 3532, 1 };
  tft.setTouch(calData);

  drawBaseLayout();
}

void drawBaseLayout() {
  tft.fillScreen(TFT_BLACK);
  
  // Header Status Bar
  tft.fillRect(0, 0, 320, 30, TFT_NAVY);
  tft.setTextColor(TFT_WHITE, TFT_NAVY);
  tft.setTextSize(2);
  tft.setCursor(10, 8);
  tft.print("CARRIE DOCK v1.0");

  // Draw Bottom Action Buttons
  // Button 1: SYNC (Blue)
  tft.fillRect(10, 185, 90, 45, TFT_BLUE);
  tft.drawRect(10, 185, 90, 45, TFT_WHITE);
  tft.setTextColor(TFT_WHITE, TFT_BLUE);
  tft.setTextSize(2);
  tft.setCursor(30, 200);
  tft.print("SYNC");

  // Button 2: EJECT (Red)
  tft.fillRect(115, 185, 90, 45, TFT_RED);
  tft.drawRect(115, 185, 90, 45, TFT_WHITE);
  tft.setTextColor(TFT_WHITE, TFT_RED);
  tft.setCursor(132, 200);
  tft.print("EJECT");

  // Button 3: LIGHTS (Green)
  tft.fillRect(220, 185, 90, 45, TFT_DARKGREEN);
  tft.drawRect(220, 185, 90, 45, TFT_WHITE);
  tft.setTextColor(TFT_WHITE, TFT_DARKGREEN);
  tft.setCursor(235, 200);
  tft.print("LIGHTS");
}

void drawTelemetry() {
  // Update header status text on the right
  tft.fillRect(200, 0, 120, 30, TFT_NAVY);
  tft.setTextSize(2);
  tft.setCursor(210, 8);
  if (currentState == STATE_DISCONNECTED) {
    tft.setTextColor(TFT_LIGHTGREY, TFT_NAVY);
    tft.print("OFFLINE");
  } else if (currentState == STATE_CONNECTED) {
    tft.setTextColor(TFT_GREEN, TFT_NAVY);
    tft.print("CONNECTED");
  } else if (currentState == STATE_SYNCING) {
    tft.setTextColor(TFT_YELLOW, TFT_NAVY);
    tft.print("SYNCING");
  } else if (currentState == STATE_SYNC_COMPLETE) {
    tft.setTextColor(TFT_GREEN, TFT_NAVY);
    tft.print("COMPLETE");
  } else if (currentState == STATE_EJECTED) {
    tft.setTextColor(TFT_RED, TFT_NAVY);
    tft.print("EJECTED");
  }

  // Draw Left Card: Charging Telemetry
  tft.drawRoundRect(10, 40, 140, 135, 8, TFT_DARKGREY);
  tft.fillRect(11, 41, 138, 133, TFT_BLACK);
  tft.setTextColor(TFT_WHITE, TFT_BLACK);
  tft.setTextSize(1);
  tft.setCursor(20, 50);
  tft.print("POWER STATUS");

  if (currentState != STATE_DISCONNECTED && currentState != STATE_EJECTED) {
    // Battery Percentage Large
    tft.setTextSize(3);
    tft.setTextColor(TFT_GREEN, TFT_BLACK);
    tft.setCursor(20, 68);
    tft.print(batteryPercent);
    tft.print("%");

    // Voltage & Current
    tft.setTextSize(1);
    tft.setTextColor(TFT_LIGHTGREY, TFT_BLACK);
    tft.setCursor(20, 105);
    tft.print("Volts: ");
    tft.print(batteryVoltage);
    tft.print("V");

    tft.setCursor(20, 125);
    tft.print("Current: ");
    tft.print(chargeCurrent);
    tft.print("mA");

    tft.setCursor(20, 145);
    tft.print(chargeCurrent > 0 ? "State: Charging" : "State: Full");
  } else {
    tft.setTextSize(2);
    tft.setTextColor(TFT_RED, TFT_BLACK);
    tft.setCursor(20, 85);
    tft.print("NO PEN");
    tft.setTextSize(1);
    tft.setTextColor(TFT_LIGHTGREY, TFT_BLACK);
    tft.setCursor(20, 120);
    tft.print("Insert device to");
    tft.setCursor(20, 135);
    tft.print("initiate docking");
  }

  // Draw Right Card: Data & Sync Status
  tft.drawRoundRect(170, 40, 140, 135, 8, TFT_DARKGREY);
  tft.fillRect(171, 41, 138, 133, TFT_BLACK);
  tft.setTextColor(TFT_WHITE, TFT_BLACK);
  tft.setTextSize(1);
  tft.setCursor(180, 50);
  tft.print("DATA ARCHIVE");

  if (currentState == STATE_SYNCING) {
    tft.setTextSize(1);
    tft.setTextColor(TFT_YELLOW, TFT_BLACK);
    tft.setCursor(180, 75);
    tft.print("UPLOADING FILES");
    
    tft.setTextColor(TFT_LIGHTGREY, TFT_BLACK);
    tft.setCursor(180, 95);
    tft.print(currentSyncFile);

    // Custom Progress Bar
    tft.drawRect(180, 120, 120, 12, TFT_WHITE);
    tft.fillRect(181, 121, (syncProgress * 118) / 100, 10, TFT_GREEN);
    
    tft.setCursor(180, 140);
    tft.print("Progress: ");
    tft.print(syncProgress);
    tft.print("%");
  } else if (currentState == STATE_SYNC_COMPLETE) {
    tft.setTextSize(2);
    tft.setTextColor(TFT_GREEN, TFT_BLACK);
    tft.setCursor(180, 80);
    tft.print("SYNC OK");
    tft.setTextSize(1);
    tft.setTextColor(TFT_LIGHTGREY, TFT_BLACK);
    tft.setCursor(180, 115);
    tft.print("All files backed up");
    tft.setCursor(180, 130);
    tft.print("to Google Drive");
  } else if (currentState == STATE_CONNECTED) {
    tft.setTextSize(2);
    tft.setTextColor(TFT_BLUE, TFT_BLACK);
    tft.setCursor(180, 80);
    tft.print("READY");
    tft.setTextSize(1);
    tft.setTextColor(TFT_LIGHTGREY, TFT_BLACK);
    tft.setCursor(180, 115);
    tft.print("Pending updates:");
    tft.setCursor(180, 130);
    tft.print("3 new recordings");
  } else {
    tft.setTextSize(2);
    tft.setTextColor(TFT_RED, TFT_BLACK);
    tft.setCursor(180, 85);
    tft.print("INACTIVE");
    tft.setTextSize(1);
    tft.setTextColor(TFT_LIGHTGREY, TFT_BLACK);
    tft.setCursor(180, 120);
    tft.print("Link connection");
    tft.setCursor(180, 135);
    tft.print("is disconnected");
  }
}

void handleTouch() {
  uint16_t x = 0, y = 0;
  
  if (tft.getTouch(&x, &y)) {
    // Debounce touch events
    if (millis() - lastTouchDebounce < 350) return;
    lastTouchDebounce = millis();

    Serial.print("Touch coordinates: X=");
    Serial.print(x);
    Serial.print(" Y=");
    Serial.println(y);

    // Touch boundaries map directly to landscape screen dimensions (320x240)
    // Check Y axis of the bottom buttons (Y: 185 to 230)
    if (y >= 185 && y <= 230) {
      // Button 1: SYNC (X: 10 to 100)
      if (x >= 10 && x <= 100) {
        Serial.println("Sync button pressed");
        if (currentState == STATE_CONNECTED || currentState == STATE_SYNC_COMPLETE) {
          currentState = STATE_SYNCING;
          syncProgress = 0;
          currentSyncFile = "video_04.h264";
        } else if (currentState == STATE_EJECTED || currentState == STATE_DISCONNECTED) {
          currentState = STATE_CONNECTED; // simulate hotplug
          batteryPercent = 78;
          batteryVoltage = 3.92;
          chargeCurrent = 420;
        }
      }
      // Button 2: EJECT (X: 115 to 205)
      else if (x >= 115 && x <= 205) {
        Serial.println("Eject button pressed");
        currentState = STATE_EJECTED;
      }
      // Button 3: LIGHTS (X: 220 to 310)
      else if (x >= 220 && x <= 310) {
        Serial.println("Lights button pressed");
        backlightOn = !backlightOn;
        // Visual indicator feedback: toggle button color state
        if (backlightOn) {
          tft.fillRect(220, 185, 90, 45, TFT_DARKGREEN);
        } else {
          tft.fillRect(220, 185, 90, 45, TFT_DARKGREY);
        }
        tft.drawRect(220, 185, 90, 45, TFT_WHITE);
        tft.setTextColor(TFT_WHITE);
        tft.setTextSize(2);
        tft.setCursor(235, 200);
        tft.print("LIGHTS");
      }
    }
  }
}

void loop() {
  handleTouch();

  // Run simulation updates every 1.5 seconds
  if (millis() - lastUpdate > 1500) {
    lastUpdate = millis();

    if (currentState == STATE_SYNCING) {
      syncProgress += 15;
      if (syncProgress >= 100) {
        syncProgress = 100;
        currentState = STATE_SYNC_COMPLETE;
      }
      
      // Simulate voltage drop during high CPU operation
      batteryVoltage = 3.85;
      chargeCurrent = 580; // drawing more power during sync
    } 
    else if (currentState == STATE_CONNECTED) {
      // Simulate standard trickle charging telemetry
      batteryPercent += 1;
      if (batteryPercent > 100) batteryPercent = 100;
      
      batteryVoltage = 4.15;
      chargeCurrent = 120; // low charging current as battery reaches top capacity
    }

    // Always redraw telemetry changes
    drawTelemetry();
  }

  // Redraw complete telemetry immediately on state change
  if (currentState != previousState) {
    drawTelemetry();
    previousState = currentState;
  }
}

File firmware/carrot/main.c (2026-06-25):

#include "gpio/gpio.h"
#include <stdio.h>
#include <unistd.h>
#include <signal.h>

#include "recorder/camera_recorder.h"


/* Allow Ctrl+C to stop recording gracefully */
static volatile int g_quit = 0;
static void on_signal(int sig) { (void)sig; g_quit = 1; }

int main() {

  // Set up signal handlers for graceful shutdown
  const char *output  = "/mnt/sdcard/DCIM/Development/recording.h264";
  signal(SIGINT,  on_signal);
  signal(SIGTERM, on_signal);
  RecorderConfig cfg = RECORDER_CONFIG_DEFAULT;


  // Configure button GPIO (Physical Header Pin 4 / GPIO 42)
  printf("Starting record detection...\n");
  int POLL_MS = 80;
  int button_gpio = 42;


  if (gpio_export(button_gpio) < 0) {
    return -1;
  }
  if (gpio_set_input(button_gpio) < 0) {
    return -1;
  }


  int previous_state = 1;
  int is_recording = 0;

  /* Continuous polling */
 

  printf("\nCleaning up...\n");
  gpio_unexport(button_gpio);

  printf("Done.\n");
  return 0;
}

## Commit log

2026-05-31 Dirt made my me
    Um this is really rudimentary, but this is just the schematic for the dirt pile. I have the footprint for the microcontroller as well.
    [dirt.kicad_pcb, dirt.kicad_sch]
2026-06-03 bill of materials update
2026-06-04 ChargerBreakoutBoard
    uh i just tried to design something, I do not know if it works.
    [BatteryCharger.kicad_pcb, BatteryCharger.kicad_sch]
2026-06-05 I added the 2 extra components to the battery regulator
    [BatteryCharger.kicad_pcb, BatteryCharger.kicad_sch]
2026-06-07 type shiii
    I added the booster converter
    [BatteryCharger.kicad_sch]
2026-06-09 Create Snap Fit Joint.f3d
    [Snap Fit Joint.f3d]
2026-06-14 i just made some changes
    [BatteryCharger.kicad_pcb, BatteryCharger.kicad_sch]
2026-06-15 Rough Draft FINISHED
    [BatteryCharger.kicad_pcb, BatteryCharger.kicad_sch]
2026-06-16 uh
    asdfasdfasdf
    [BatteryCharger-B_Cu.gbl, BatteryCharger-B_Mask.gbs, BatteryCharger-B_Paste.gbp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]
2026-06-18 i created some edits and added the zine
    [dirt.kicad_pcb, dirt.kicad_sch]
2026-06-18 charger has been finished final draft
    [BatteryCharger.kicad_pcb, Carry.kicad_pcb, Carry.kicad_sch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]
2026-06-18 dirt finished
    [Carry.kicad_pcb, dirt.kicad_pcb]
2026-06-18 finished all PCB awaiting checkup
    [Carry.kicad_pcb, Carry.kicad_sch]
2026-06-18 added cad shit
    [Battery Holder.f3d, Battery Holder.step, Camera Support.f3d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]
2026-06-19 more site stuff + zine/BOM
    [Bill of Materials.csv]
2026-06-19 Update README with software and hardware details
    Added sections on software, firmware, and hardware architecture for the carrot pen and pot. Included details on power management, data transfer, and display components.
2026-06-19 fix for submission prescan
    [.step, Battery Holder.f3d, Battery Holder.step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]
2026-06-23 Update part links in bill_of_materials.csv
    [bill_of_materials.csv]
2026-06-23 Add bill of materials reference to README
    Added a reference to the bill of materials in the documentation.
2026-06-25 stuff
    Removed comments and cleaned up code in display driver.
2026-06-25 yo i forgor to delete the template readme lol
    deleted template readme and rework some docs to be less boilerplated
    [displaydriver.ino, gpio.c, main.c]
2026-06-25 Restore README.md and bill of materials from origin/main, retaining local comment cleanups
    [bill_of_materials.csv]
2026-06-25 i screwed up the git but i got it fixed now i delete readme
